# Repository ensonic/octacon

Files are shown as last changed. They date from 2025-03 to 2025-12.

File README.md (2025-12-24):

# Octacon
A midi controller tailored for bitwig with 8 endless pots, 8 buttons, 8 leds, 2 displays and a touch sensor.

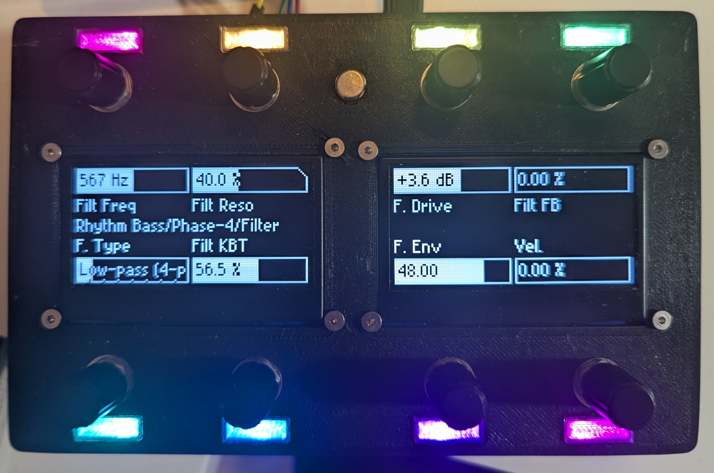
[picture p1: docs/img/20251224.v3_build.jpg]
wip image of the day


The latest [video tour](https://www.youtube.com/watch?v=5QIr6vOy6ok) can be watched on youtube.

# Getting started

## Flashing a release

* download and install [pictool](https://github.com/raspberrypi/picotool)
* download an octacon [firmware release](https://github.com/ensonic/octacon/releases) or [build it yourself](#code)
* connect octacon to usb
* flash the device using this command under linux:
  ```shell
  stty 1200 /dev/ttyACM0 && sleep 2 && picotool load -f ~/Downloads/firmware.uf2 && picotool reboot
  ```

## Installing the extension

Download an octacon [daw extension](https://github.com/ensonic/octacon/releases)
or [build it yourself](#code) and copy it into the `Extensions` folder of your
Bitwig Studio installation:
* Linux: ~/Bitwig Studio/Extensions/
* Mac: ~/Documents/Bitwig Studio/Extensions/
* Windows: %USERPROFILE%\Documents\Bitwig Studio\Extensions\

For Bitwig Studio > 3.4, you can also drag the file from your downloads into the Bitwig Studio window.

In Bitwig Studio, go to Settings > Controller and add a new one. Pick `ensonic`
as the vendor and select `Octacon` as the hardware. Ensure both midi ports have
`Octacon` or `Octacon MIDI 1` selected.

## Usage

TODO:
* active/passive mode
* control and navigation mode

# Hardware & Firmware

* raspberry pico 2
* 8 endless dual wiper potentiometers with buttons (RV142FPF-40B1-15F-0B20K-004)
* 3 analog multiplexers (e.g. CD74HC4051)
* 8 NeoPixel LEDs (WS2812x)
* 2 128x64 OLED displays connected via SPI
* 1 capacitive touch control

The `pcb` subfolder has the the schematics and the pcb files for [easyeda](https://easyeda.com/).
You should be able to import them into the Std Edition.

## Enclosure

The `3d` subfolder has openScad files and rendered STL for 3d printing.

The front_test.scad is mostly for prototyping:
Front view | Side View
:---------:|:---------:
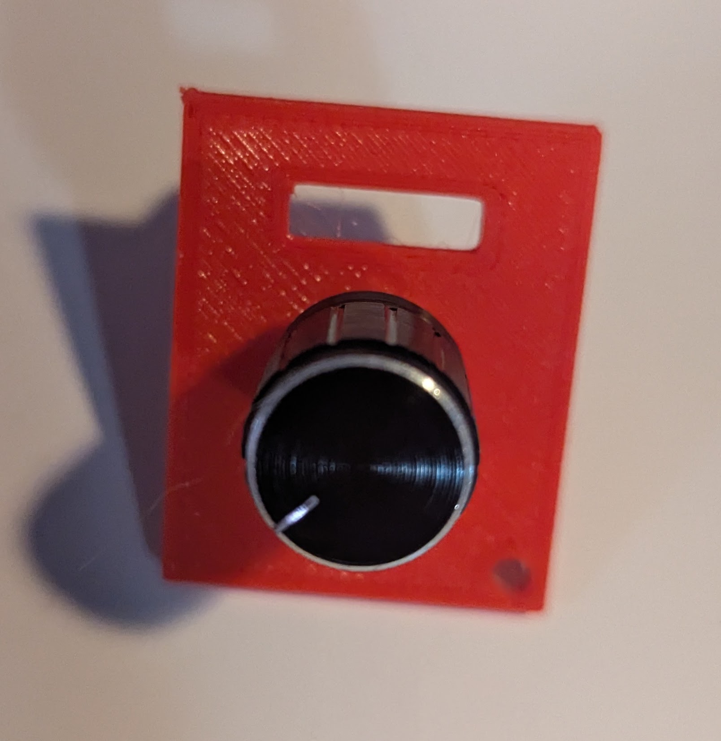
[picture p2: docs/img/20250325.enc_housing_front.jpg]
front
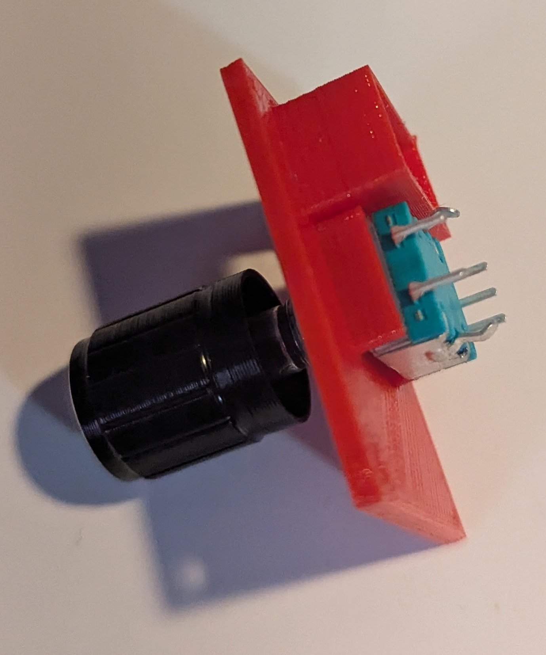
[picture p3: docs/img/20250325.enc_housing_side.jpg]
 | 

## MIDI implementation

Under Linux you can watch the communication using `asqedump`:

```shell
aseqdump -l | grep Octacon
 32:0    Octacon                          Octacon MIDI 1
aseqdump -p32:0
Source  Event                  Ch  Data
 32:0   Control change          0, controller 9, value 51
 32:0   Control change          0, controller 9, value 52
```

### Control changes

The encoders send 7bit values on cc 9 to 16. In 14-bit mode, the lsb is send on
cc 41 to 49.
The encoder buttons send values {0=off, 64=on} on cc 17 to 25.

### Sysex

Since Octacon uses usb midi and is a hobby project, we're using the `7D`
(prototyping, test, private use and experimentation). 

The following commands are implemented:
* 00: (recv) parameter names: `00 + <ix> + <len> + <name>`
  * id: 0...7
  * len: len of name, truncated to fit the display
  * name: ascii string data
* 01: (recv) pretty parameter value: `01 + <ix> + <len> + <name>`
  * id: 0...7
  * len: len of name, truncated to fit the display
  * name: ascii string data
* 02: (recv) daw connected? : `02 + <connected>`
  * connected: 0 = off, anything else = on
  * when off, parameter names and pretty values are generated
* 03: (recv) led pattern: `03 + <pattern>`
* 04: (recv) info string: `04 + <len> + <text>`
* 05: (recv) param ticks: `05 + <ix> <value>`
* 06: (recv) param flags: `05 + <ix> <flags>`
  * flags: bit field of:
    * 0: hasAutomation

# Code

## Firmware

The code uses [platformIO](https://platformio.org/). See [platformio.ini](platformio.ini) for the used libraries.

```shell
alias pio=$HOME/.platformio/penv/bin/pio
pio test
pio run -t upload
```

With regards to flashing from command-line, see:
  * https://github.com/maxgerhardt/platform-raspberrypi/issues/65
  * https://github.com/raspberrypi/picotool/issues/88

## DAW Extensions

The daw extension for Bitwig is written in java.

```shell
cd daw/bitwig
mvn install
```

# Debugging

Since we're using usb-midi, we can't use it for serial logging at the same time. I am simply using a nodemcu esp8266 as serial2. On the nodemcu connect EN to GND to disable the ESP. Then connect the nodemcu to the pico2 as follow:
nodemcu esp8266 | raspberry pico2 
:--------------:|:---------------:
GND  | GND
3.3V | 3.3V (optional)
TX   | UART1 TX, pin 6 
RX   | UART1 RX, pin 7

Now plug the nodemcu to usb and open /dev/ttyUSB0 to see the serial log.

# Links

I've got inspiration from many other places. Let me mention a few similar
projects:
* [Ottopot](https://gerotakke.de/ottopot/)

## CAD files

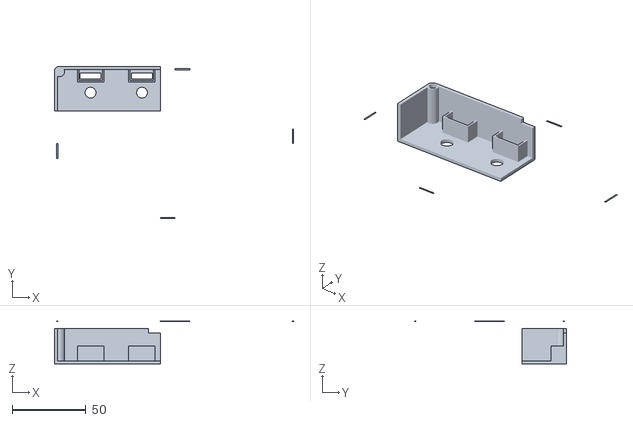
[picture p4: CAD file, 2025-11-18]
3d/v2/front.test.stl
162.6 x 103.4 x 29.1

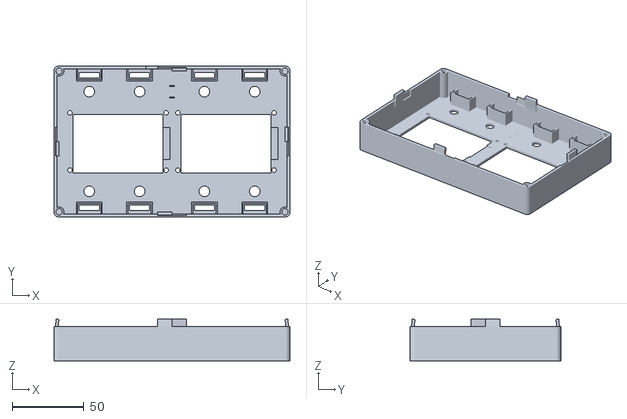
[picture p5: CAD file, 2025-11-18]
3d/v2/front.stl
164.0 x 104.8 x 29.1

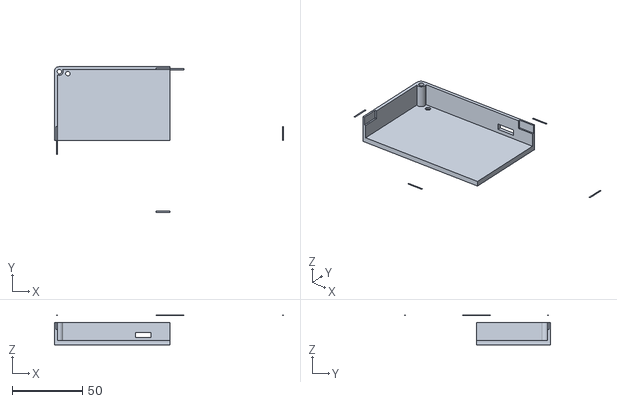
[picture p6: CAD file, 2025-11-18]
3d/v2/back.test.stl
162.6 x 103.4 x 21.1

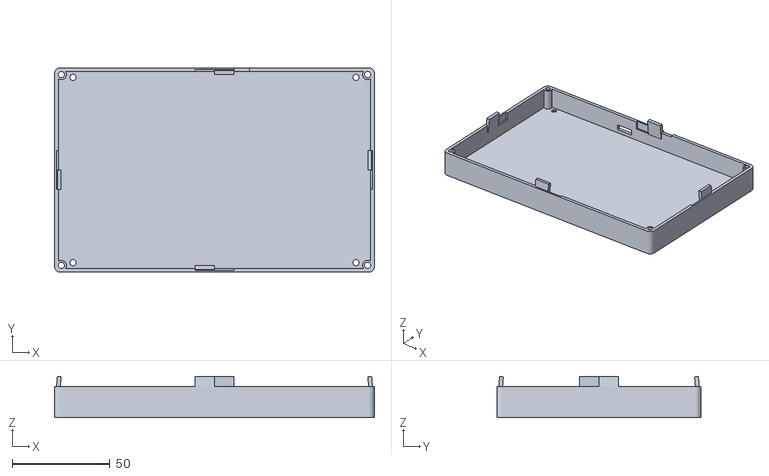
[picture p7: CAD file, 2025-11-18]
3d/v2/back.stl
164.0 x 104.8 x 21.1

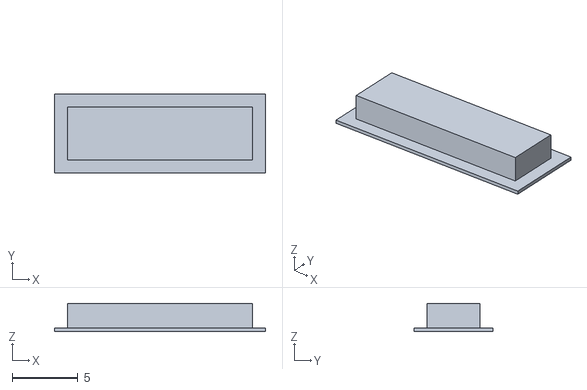
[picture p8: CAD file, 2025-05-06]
3d/v2/led.stl
16.0 x 6.00 x 2.12

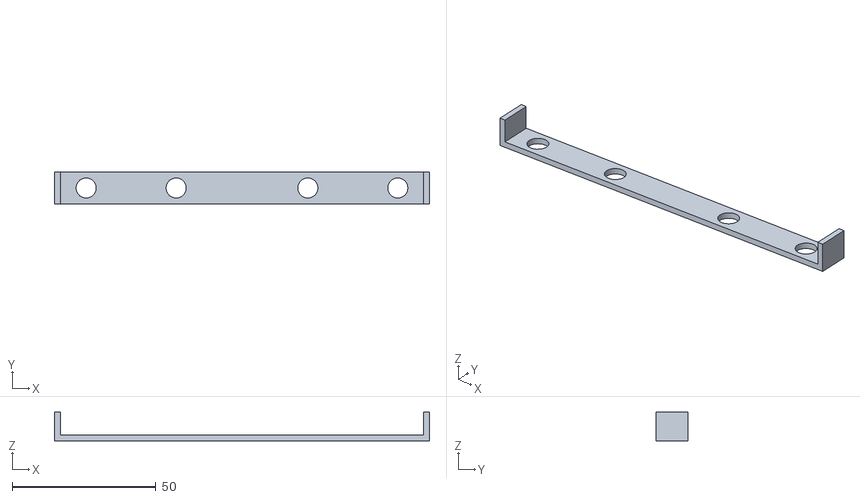
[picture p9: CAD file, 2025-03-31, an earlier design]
3d/v1/led_bracket.stl
130.2 x 11.0 x 10.0

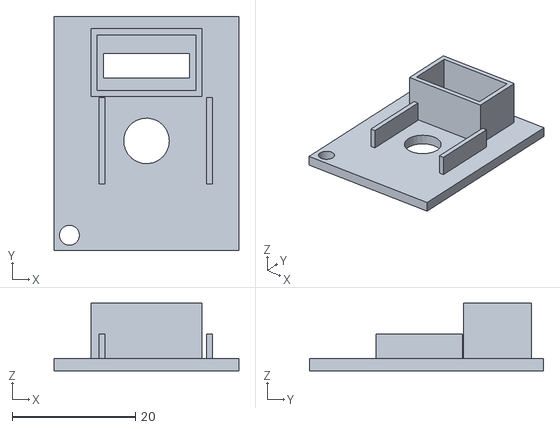
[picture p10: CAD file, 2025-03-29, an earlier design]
3d/v1/front_test.stl
30.0 x 38.0 x 11.0

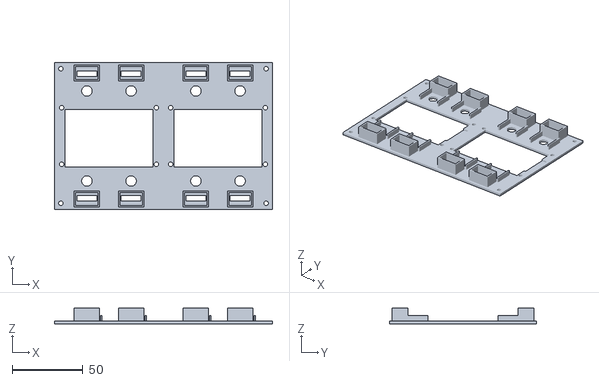
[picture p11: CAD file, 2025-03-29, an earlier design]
3d/v1/front.stl
154.0 x 104.0 x 11.0

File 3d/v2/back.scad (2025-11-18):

// octacon bottom case
// openscad -o back.stl back.scad
// f3d back.stl

// might be overridden by the Makefile to generate partial object
test=false;
if (test==true) {
    echo("TEST MODE ACTIVE", test);
}

// wall thickness
wd=2.0;
wd2=wd/2.0;

// case size
casew=160.0 + (2 * wd);
casew2=casew/2.0;
casehs=0.8; // leave some space to make the pcb fit
caseh=100.0 + (2 * wd) + casehs; 
caseh2=caseh/2.0;
// 20 mm screw - 4mm for inserts on the other side
// 16 mm is enough to hold the base pcb with the pico-2
cased=20-4;
cased2=cased/2.0;

// pcb size
pcbw=150.0;
pcbw2=pcbw/2.0;
pcbh=100.0;
pcbh2=pcbh/2.0;

// corners
corr=3;
cord=corr*2;
coff=corr/2;

// m3 screw holes
m3d=3.2; // extra size to cover 3d print thickness

// make it smooth
$fn=25;

difference() {
    union() {
        difference() {
            // main body
            cube([casew,caseh,cased],center=true);

            // space for inside
            translate([0,0,wd]) { cube([casew - (2.0 * wd), caseh - (2.0 * wd), cased-wd],center=true); }
            
            // rounded corners
            translate([-(casew2-corr),-(caseh2-corr),0]) { round_corner(cased+5, cord, -coff, -coff); }
            translate([+(casew2-corr),-(caseh2-corr),0]) { round_corner(cased+5, cord, +coff, -coff); }
            translate([-(casew2-corr),+(caseh2-corr),0]) { round_corner(cased+5, cord, -coff, +coff); }
            translate([+(casew2-corr),+(caseh2-corr),0]) { round_corner(cased+5, cord, +coff, +coff); }

            // holes for case screws
            translate([-(casew2-3.5),-(caseh2-3.5),0]) { screw_hole(cased, m3d); }
            translate([+(casew2-3.5),-(caseh2-3.5),0]) { screw_hole(cased, m3d); }
            translate([-(casew2-3.5),+(caseh2-3.5),0]) { screw_hole(cased, m3d); }
            translate([+(casew2-3.5),+(caseh2-3.5),0]) { screw_hole(cased, m3d); }
            
            // holes for base screws
            translate([-(pcbw2-2.5),-(pcbh2-2.5),0]) { screw_hole(cased, m3d); }
            translate([+(pcbw2-2.5),-(pcbh2-2.5),0]) { screw_hole(cased, m3d); }
            translate([-(pcbw2-2.5),+(pcbh2-2.5),0]) { screw_hole(cased, m3d); }
            translate([+(pcbw2-2.5),+(pcbh2-2.5),0]) { screw_hole(cased, m3d); }
            
            // usb hole (in inch grid: ~ 33-37)
            // micro-b plug body: max 11.7 mm * 8.5 mm
            // micro-b plug: 7mm x 3mm
            // on the pico-2 the micro-usb socket extends ~ 2mm beyond the board
            // hence leaving space for the plug should be enough
            // from the base of the board to top of the usb it is 16mm
            // TODO: we might need so hole on the front side too
            // z: 14mm - (cased2 - wd)
            // x (just need the middle): startpin=33, -1 (to start a zero), +3 (to get middle of the 6 pins)
            translate([-(pcbw2-((33-1)+3)*2.54),+caseh2, 15-(cased2-wd)]) { cube([8.0, wd*4, 4], center=true);}

            // debug header hole (in inch grid: 21-24)
            // 11.0 x 3.0 mm
            // the debug headers extend ~ 1 mm beyond the pcb
            // startpin=21, -1 (to start a zero), +2 (to get middle of the 4 pins)
            translate([-(pcbw2-((21-1)+2)*2.54),+caseh2,-cased2+(wd+5)]) { cube([11.0, wd*4, 3.5], center=true);}
            
            // groves for the matching ridges on the bottom
            translate([-(casew2-wd),+5,cased2]) { cube([wd,10,10], center=true); }
            translate([+(casew2-wd),-5,cased2]) { cube([wd,10,10], center=true); }
            translate([+5,-(caseh2-wd),cased2]) { cube([10,wd,10], center=true); }
            translate([-5,+(caseh2-wd),cased2]) { cube([10,wd,10], center=true); }
        }

        // tubes for case screws
        // 3.5 == (wd + wd) - .5 (thickness of screen wall / 2)
        translate([-(casew2-3.5),-(caseh2-3.5),wd2]) { screw_tube(cased-wd, m3d); }
        translate([+(casew2-3.5),-(caseh2-3.5),wd2]) { screw_tube(cased-wd, m3d); }
        translate([-(casew2-3.5),+(caseh2-3.5),wd2]) { screw_tube(cased-wd, m3d); }
        translate([+(casew2-3.5),+(caseh2-3.5),wd2]) { screw_tube(cased-wd, m3d); }

        // ridges for the matching groves on the bottom
        translate([-(casew2-wd),-5,cased2]) { rotate([0,+5,0]) { cube([wd,10,10], center=true); }}
        translate([+(casew2-wd),+5,cased2]) { rotate([0,-5,0]) { cube([wd,10,10], center=true); }}
        translate([-5,-(caseh2-wd),cased2]) { rotate([-5,0,0]) { cube([10,wd,10], center=true); }}
        translate([+5,+(caseh2-wd),cased2]) { rotate([+5,0,0]) { cube([10,wd,10], center=true); }}
    }

    // in test-mode generate only parts of the case
    translate([(test==true ? 0 : casew*10), 0, 0]) {
        translate([casew2,0,0]) { cube([casew, caseh+10, cased+10], center=true); }
        translate([0,-caseh2,0]) { cube([casew+10, caseh, cased+10], center=true); }
    }
}

module round_corner(h, d, x, y) {
    r=d/2;
    difference() {
        translate([x,y,0]) { cube([r+0.1,r+0.1,h], center=true); }
        cylinder(h=h+2, d=d, center=true);
    }    
}

module screw_tube(h, d) {
    difference() {
        cylinder(h=h, d=d+2, center=true);
        cylinder(h=h+2, d=d, center=true);
    }
}

module screw_hole(h, d) {
    union() {
        cylinder(h=h+5, d=d, center=true);
        translate([0, 0, -(h-wd)/2]) { cylinder(h=wd+.1, d1=d*2, d2=d, center=true); }
    }
}

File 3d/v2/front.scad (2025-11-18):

// octacon frontpanel
// openscad -o front.stl front.scad
// f3d front.stl

// might be overridden by the Makefile to generate partial object
test=false;
if (test==true) {
    echo("TEST MODE ACTIVE", test);
}

// wall thickness
wd=2.0;
wd2=wd/2.0;

// case size
casew=160.0 + (2 * wd);
casew2=casew/2.0;
casehs=0.8; // leave some space to make the pcb fit
casehs2=casehs/2.0;
caseh=100.0 + (2 * wd) + casehs; 
caseh2=caseh/2.0;
// 4mm for inserts, 16mm from top of panel to FPC mount
cased=24;
cased2=cased/2.0;

// pcb size
pcbw=150.0;
pcbw2=pcbw/2.0;
pcbw4=pcbw/4.0;
pcbh=100.0;
pcbh2=pcbh/2.0;

// display box
dw=62.5;
dw2=dw/2.0;
dw4=dw/4.0;
dh=40.5;
dh2=dh/2.0;
// display breakout board 
dbw=71;
dbw2=dbw/2.0;
dbh=44;
dbh2=dbh/2.0;
// account for asymmetric placement of display on breakout board
// dbh-dh = 3.5 : 3mm top, 0.5 mm bottom 
dho=-(3.0/2.0);

// led/pot positions on pcb
lppx1=17.5;
lppx2=52.5;
ppy=15.35;

// Alpha dual wiper potentiometers
ew=14.4;
eh1=9.7;
eh2=6.7;
eh=eh1+eh2;
eho=eh1-(eh/2.0); // shaft offset to center
er=3.7;  // shaft
// was 31.8, is now 34,65
em=pcbh2-ppy;

// leds
lw=14;
lh=4;
// pcb 2.2 mm space + 4 mm led hole
lm=46; // we need to cover 6mm from the top of the led&pots pcb
// with 13, we had only 7mm to the surface
// with 12.5 we have ~1 mm gap between pot & pcb
lsh=12.0;
lsh2=lsh/2.0;
lsg2=2;

// corners
corr=3;
cord=corr*2;
coff=corr/2;

// m3 screw holes
m3d=3.2; // extra size to cover 3d print thickness
m3r=m3d/2;
m3sd=.5+m3r;
// m4 insert holes
m4d=4.5;

// threaded inserts: outer diameter 5mm, depth 4mm

// make it smooth
$fn=25;

difference() {
    union() {
        difference() {
            // main body
            cube([casew,caseh,cased],center=true);

            // space for inside
            translate([0,0,wd]) { cube([casew - (2.0 * wd), caseh - (2.0 * wd), cased],center=true); }
            
            // rounded corners
            translate([-(casew2-corr),-(caseh2-corr),0]) { round_corner(cased+5, cord, -coff, -coff); }
            translate([+(casew2-corr),-(caseh2-corr),0]) { round_corner(cased+5, cord, +coff, -coff); }
            translate([-(casew2-corr),+(caseh2-corr),0]) { round_corner(cased+5, cord, -coff, +coff); }
            translate([+(casew2-corr),+(caseh2-corr),0]) { round_corner(cased+5, cord, +coff, +coff); }

            // displays
            translate([-pcbw4,  dho,0]) { cube([dw,dh,cased+5], center=true); }
            translate([-pcbw4+5,dho,.5]) { cube([dw,(dh*0.55),cased-1], center=true); }
            translate([+pcbw4,  dho,0]) { cube([dw,dh,cased+5], center=true); }
            translate([+pcbw4+5,dho,.5]) { cube([dw,(dh*0.55),cased-1], center=true); }

            // M3 holes for displays
            // left
            translate([-(pcbw4-(dbw2-m3sd)),-(dbh2-m3sd),0]) { cylinder(h=cased+5,r=m3r, center=true); }
            translate([-(pcbw4-(dbw2-m3sd)),+(dbh2-m3sd),0]) { cylinder(h=cased+5,r=m3r, center=true); }
            translate([-(pcbw4+(dbw2-m3sd)),-(dbh2-m3sd),0]) { cylinder(h=cased+5,r=m3r, center=true); }
            translate([-(pcbw4+(dbw2-m3sd)),+(dbh2-m3sd),0]) { cylinder(h=cased+5,r=m3r, center=true); }
            // right
            translate([+(pcbw4-(dbw2-m3sd)),-(dbh2-m3sd),0]) { cylinder(h=cased+5,r=m3r, center=true); }
            translate([+(pcbw4-(dbw2-m3sd)),+(dbh2-m3sd),0]) { cylinder(h=cased+5,r=m3r, center=true); }
            translate([+(pcbw4+(dbw2-m3sd)),-(dbh2-m3sd),0]) { cylinder(h=cased+5,r=m3r, center=true); }
            translate([+(pcbw4+(dbw2-m3sd)),+(dbh2-m3sd),0]) { cylinder(h=cased+5,r=m3r, center=true); }


            // leds
            // bottom row
            translate([0,-lm,0]) { 
                translate([-pcbw2+lppx2,0.0]) { cube([lw,lh,cased+5], center=true); }
                translate([-pcbw2+lppx1,0.0]) { cube([lw,lh,cased+5], center=true); }
                translate([+pcbw2-lppx2,0.0]) { cube([lw,lh,cased+5], center=true); }
                translate([+pcbw2-lppx1,0.0]) { cube([lw,lh,cased+5], center=true); }
            }
            // top row
            translate([0,lm,0]) { 
                translate([-pcbw2+lppx2,0.0]) { cube([lw,lh,cased+5], center=true); }
                translate([-pcbw2+lppx1,0.0]) { cube([lw,lh,cased+5], center=true); }
                translate([+pcbw2-lppx2,0.0]) { cube([lw,lh,cased+5], center=true); }
                translate([+pcbw2-lppx1,0.0]) { cube([lw,lh,cased+5], center=true); }
            }

            // potentiometers
            // bottom row
            translate([0,-em,0]) { 
                translate([-pcbw2+lppx2,0,0]) { cylinder(h=cased+5,r=er, center=true); }
                translate([-pcbw2+lppx1,0,0]) { cylinder(h=cased+5,r=er, center=true); }
                translate([+pcbw2-lppx2,0,0]) { cylinder(h=cased+5,r=er, center=true); }
                translate([+pcbw2-lppx1,0,0]) { cylinder(h=cased+5,r=er, center=true); }
            }
            // top row
            translate([0,em,0]) { 
                translate([-pcbw2+lppx2,0,0]) { cylinder(h=cased+5,r=er, center=true); }
                translate([-pcbw2+lppx1,0,0]) { cylinder(h=cased+5,r=er, center=true); }
                translate([+pcbw2-lppx2,0,0]) { cylinder(h=cased+5,r=er, center=true); }
                translate([+pcbw2-lppx1,0,0]) { cylinder(h=cased+5,r=er, center=true); }
            }

            // tube-holes for case-inserts
            translate([-(casew2-3.5),-(caseh2-3.5),wd2]) { insert_tube_hole(cased-wd, m4d); }
            translate([+(casew2-3.5),-(caseh2-3.5),wd2]) { insert_tube_hole(cased-wd, m4d); }
            translate([-(casew2-3.5),+(caseh2-3.5),wd2]) { insert_tube_hole(cased-wd, m4d); }
            translate([+(casew2-3.5),+(caseh2-3.5),wd2]) { insert_tube_hole(cased-wd, m4d); }

            // groves for the matching ridges on the bottom
            translate([-(casew2-wd),+5,cased2]) { cube([wd,10,10], center=true); }
            translate([+(casew2-wd),-5,cased2]) { cube([wd,10,10], center=true); }
            translate([+5,-(caseh2-wd),cased2]) { cube([10,wd,10], center=true); }
            translate([-5,+(caseh2-wd),cased2]) { cube([10,wd,10], center=true); }

            // holes for split pin legs: 8mm apart, 3mm width, 
            // position so that we can bend the legs to the middle
            translate([0,em-4,0]) { cube([3.5,0.6,cased+10], center=true); }
            translate([0,em+4,0]) { cube([3.5,0.6,cased+10], center=true); }
            
            // usb hole (see back.scad for positioning, nneds to be x-flipped!)
            translate([+(pcbw2-((33-1)+3)*2.54),+caseh2, (cased-3.0)-(cased2-wd)]) { cube([8.0, wd*4, 4], center=true);}
            
        }

        // tubes for case screw inserts
        // 3.5 == (wd + wd) - .5 (thickness of screen wall / 2)
        translate([-(casew2-3.5),-(caseh2-3.5),wd2]) { insert_tube(cased-wd, m4d); }
        translate([+(casew2-3.5),-(caseh2-3.5),wd2]) { insert_tube(cased-wd, m4d); }
        translate([-(casew2-3.5),+(caseh2-3.5),wd2]) { insert_tube(cased-wd, m4d); }
        translate([+(casew2-3.5),+(caseh2-3.5),wd2]) { insert_tube(cased-wd, m4d); }

        // led boxes
        // bottom row
        translate([0,-(lm+lsg2-1),-(cased2-lsh2)]) {
            translate([-pcbw2+lppx2,0,0]) { led_shield(); }
            translate([-pcbw2+lppx1,0,0]) { led_shield(); }
            translate([+pcbw2-lppx2,0,0]) { led_shield(); }
            translate([+pcbw2-lppx1,0,0]) { led_shield(); }
        }
        // top row
        translate([0,+(lm+lsg2-1),-(cased2-lsh2)]) {
            translate([-pcbw2+lppx2,0,0]) { led_shield(); }
            translate([-pcbw2+lppx1,0,0]) { led_shield(); }
            translate([+pcbw2-lppx2,0,0]) { led_shield(); }
            translate([+pcbw2-lppx1,0,0]) { led_shield(); }
        }       

        // ridges for the matching groves on the bottom
        translate([-(casew2-wd),-5,cased2]) { rotate([0,+5,0]) { cube([wd,10,10], center=true); }}
        translate([+(casew2-wd),+5,cased2]) { rotate([0,-5,0]) { cube([wd,10,10], center=true); }}
        translate([-5,-(caseh2-wd),cased2]) { rotate([-5,0,0]) { cube([10,wd,10], center=true); }}
        translate([+5,+(caseh2-wd),cased2]) { rotate([+5,0,0]) { cube([10,wd,10], center=true); }}
    }

    // in test-mode generate only parts of the case
    translate([(test==true ? 0 : casew*10), 0, 0]) {
        // +6 to have the full split-pins in there
        //translate([casew2+6,0,0]) { cube([casew, caseh+10, cased+10], center=true); }
        translate([casew2-10,0,0]) { cube([casew, caseh+10, cased+10], center=true); }
        translate([0,22-caseh2,0]) { cube([casew+10, caseh, cased+10], center=true); }
    }
}

// modules

module round_corner(h, d, x, y) {
    r=d/2;
    difference() {
        translate([x,y,0]) { cube([r+0.1,r+0.1,h], center=true); }
        cylinder(h=h+2, d=d, center=true);
    }    
}
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

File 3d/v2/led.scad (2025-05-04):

// octacon led diffusor
// alias openscad=~/Applications/OpenSCAD-2021.01-x86_64.AppImage
// openscad -o led.stl led.scad
// f3d led.stl
//
// slicer settings:
// - normal (0.15mm)
// - infill pattern=tri-hexagon
//
// Use transparent PLA

// wall thickness
wd=2.0;

// leds
lw=14;
lh=4;

union() {
    cube([lw,lh, wd], center=true);
    translate([0,0,-wd/2]) { cube([lw+2,lh+2,0.25],center=true); }
}

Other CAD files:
3d/v1/front.scad
3d/v1/front_test.scad
3d/v1/led_bracket.scad

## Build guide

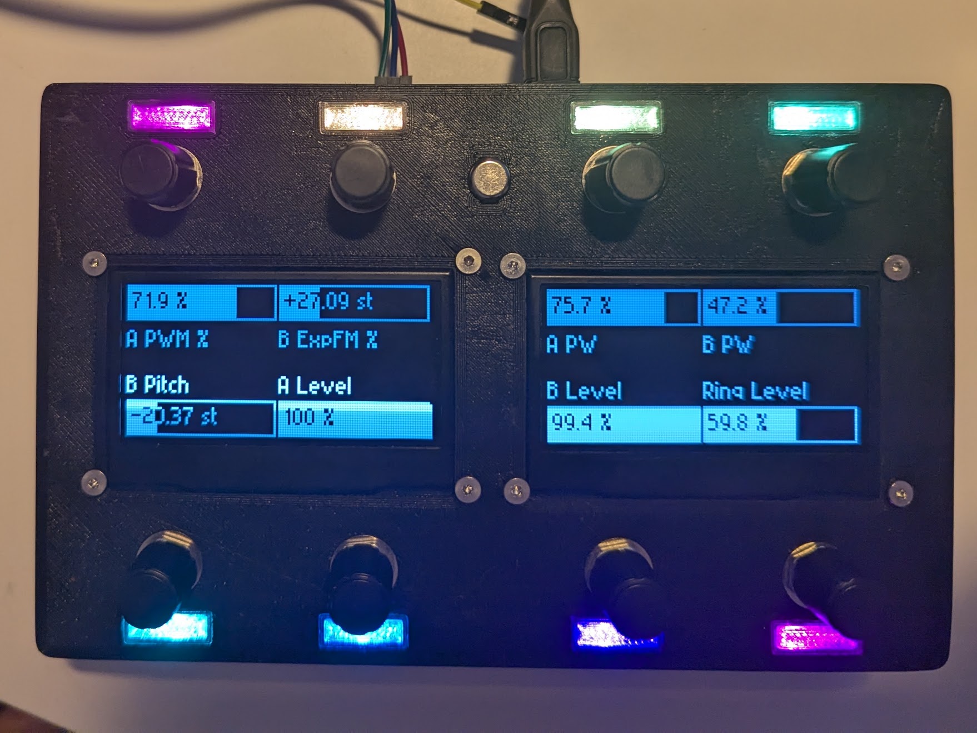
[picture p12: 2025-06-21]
docs/img/20250614.v3_build.jpg

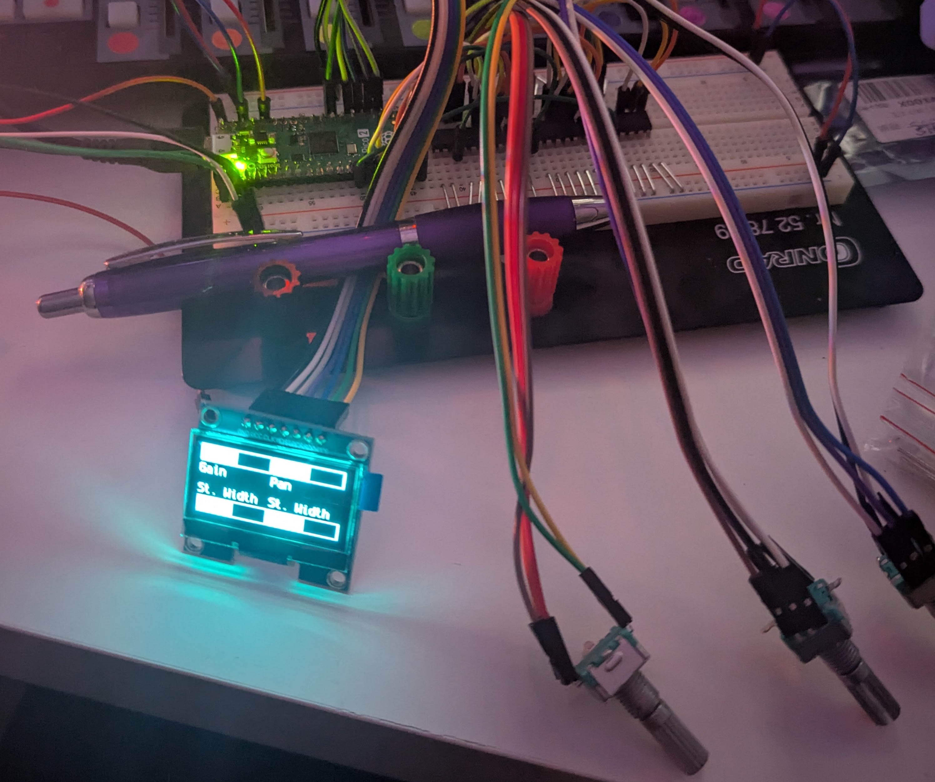
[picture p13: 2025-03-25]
docs/img/20250325.proto_build.jpg

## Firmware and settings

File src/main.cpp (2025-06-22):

// octacon midi controller

#include <config.h>

// hardware variant to build
#if HW_VER == 1
#include <hw.v1.h>
#elif HW_VER == 2
#include <hw.v2.h>
#endif


static boolean active = false;

// callbacks

static void valueCB(unsigned int ix,int value,int delta) {
    if (!active) return;
    dbg.printf("Knob[%u]: Value = %d | Delta = %d\n", ix, value, delta);
    ui.setValue(ix, value);
    mio.sendValueCC(ix, value);
}

static void buttonCB(unsigned int ix, int state) {
    if (!active) return;
    dbg.printf("Button:[%u]; State= %d\n", ix, state);
    mio.sendButtonCC(ix, state*64);
}

void setup() {
    unsigned long ts0 = millis();
    leds.begin(); // call early to reset to black
    mio.init(); // call early to ensure usb-id is set

    dbg.init();
    dbg.println("Setup start");

    pinMode(LED_BUILTIN, OUTPUT);

    ui.init();

    knobs.setLimits(0,VAL_MAX);
    knobs.setValue(VAL_MAX/2);
    knobs.attachButtonCallback(buttonCB);
    knobs.attachValueCallback(valueCB);
    knobs.begin();

    capsense.begin();

    leds.setBrightness(0.05);
    ui.begin();
    dbg.printf("Setup done: %u ms\n", millis()-ts0);
}

// run midi at full speed
// don't poll the knobs too quickly though
void loop() {
    unsigned long m=millis();
    static unsigned long tk = 0;
    if (m - tk > 20) {
        knobs.tick();
        tk = m;
    }

    mio.tick();

    static unsigned long tb = 0;
    static bool blink = false;
    if (m - tb > 500)  {
        digitalWrite(LED_BUILTIN, blink);
        blink = !blink;
        tb = m;
        /* DEBUG
        leds.SetBrightness((blink ? 0.2 : 0.3));
        */
    }

    static unsigned long tt = 0;
    static unsigned long touch_wait = 0;
    static boolean touched = false;
    if (m - tt > touch_wait)  {
        touch_wait = 0;
        // csv is the discharge time, if long, the sensor has been touched
        unsigned long csv = capsense.touch();
        //dbg.printf("CapSensor: %lf µs\n", csv);
        if (!touched && csv > 1000) {
            touched = true;
            touch_wait = 250;
            dbg.printf("CapSensor: touch    : %lu µs\n", csv);
            active = !active;
            leds.setBrightness(active ? 0.3 : 0.05);
        } else if (touched && csv < 250) {
            touched = false;
            touch_wait = 250;
            dbg.printf("CapSensor: released : %lu µs\n", csv);
        }
        tt = m;
    }
}

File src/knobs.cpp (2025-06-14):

// knob handlers code

#include <debug.h>
#include <knobs.h>

#include <math.h>

extern Debug dbg;

// use analogReadResolution(12); to activate this resolution, default is 10
static const int ADC_100_PCT = (1<<12);
static const int ADC_50_PCT = (ADC_100_PCT>>1);

/* which pot to debug (press button to switch)
static int dbgix=0;
static int vami=ADC_100_PCT,vama=0;
static int vbmi=ADC_100_PCT,vbma=0;
*/

Knobs::Knobs(admux::Mux *vala,admux::Mux *valb, admux::Mux *btn, int8_t *kmap) : vala(vala), valb(valb), btn(btn) , kmap(kmap) {
    float threshold_pct = (float)threshold / (float)ADC_100_PCT;
    for (unsigned i = 0; i < numParams; i++) {
        pots[i].threshold = threshold_pct;
    }
}

void Knobs::begin(void) {
    analogReadResolution(12);
    tick();
}

void Knobs::tick(void) {
    for (unsigned i = 0; i < numParams; i++) {
        // it is enough to drive one multiplexer address, as we use the same 
        // S{0,1,2} pins for all 3 multiplexers
        /*
        */
        vala->channel(kmap[i]);
        delayMicroseconds(1); // let  ADC settle

        auto va = mavgA[i].update(vala->read());
        auto vb = mavgB[i].update(valb->read());
       
        // see plot.py
        /*if (i==0) {
            dbg.printf("plt:%d,%d\n", va, vb);
        }*/
        /* DEBUG
        if (i == dbgix) {
            if (va > vama) vama=va;
            else if (va < vami) vami=va;
            if (vb > vbma) vbma=vb;
            else if (vb < vbmi) vbmi=vb;
        } */

        float vaf = (float)(va-ADC_50_PCT)/(float)ADC_50_PCT;
        float vbf = (float)(vb-ADC_50_PCT)/(float)ADC_50_PCT;
        int delta = scale * pots[i].update(vaf, vbf);
        if (vcb && abs(delta) > 0) {
            lastTs[i] = millis();
            int v=values[i];
            if ( v + delta > maxV) {
                //dbg.printf("clip upper: %d + %d\n", v, delta);
                delta = maxV - values[i];
            } else if (v + delta < minV) {
                //dbg.printf("clip lower: %d + %d\n", v, delta);
                delta = minV - values[i];
            }
            if (abs(delta) > 0) {
                v += delta;
                vcb(i, v, delta);
                /* DEBUG
                if (i == dbgix) {
                    dbg.printf("%1d: v=%5d, d=%+5d, va=%5d..%5d..%5d, vb=%5d..%5d..%5d\n",
                        i, v, delta, vami,va, vama, vbmi, vb, vbma);
                } */
            }
            values[i] = v;
        }
 
        auto button = btn->read();
        if (bcb && button != buttons[i]) {
            buttons[i] = button;
            bcb(i, button);
            /* DEBUG
            if (button == 0) {
                vami=vbmi=ADC_100_PCT;
                vama=vbma=0;
                dbgix = i;
            } */
        }
    }    
}

void Knobs::setLimits(int mi, int ma) {
    minV = mi;
    maxV = ma;
    scale = (float)((1+ma)-mi);
}

void Knobs::setValue(int val) {
    for (unsigned i = 0; i < numParams; i++) {
       values[i] = val;
    }
}

void Knobs::setValue(unsigned ix, int val) {
    if ((millis() - lastTs[ix]) < 100) return;

    values[ix] = val;
}

int Knobs::getValue(unsigned ix) {
    return values[ix];
}

void Knobs::attachValueCallback(valueCallback_t callback) {
    vcb = callback;
}

void Knobs::attachButtonCallback(buttonCallback_t callback) {
    bcb = callback;
}

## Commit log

2025-03-23 Add draft for front-panel.
    [front.scad, front.stl]
2025-03-23 Initial display layout.
    Draw actual values for the first 4 encoders.
2025-03-24 Switch to bitwig colors.
    Switch leds to use bitwig colors.
2025-03-24 Improve the 3d models.
    Add a small version of the front-panel for testing. Add a led-holder.
    [front.scad, front.stl, front_test.scad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]
2025-03-24 Update parameter handling.
    * drop color led changes (was only temp for debugging)
    * prep draw code to get param names and do ix mappiing
    * init params from midi cc
2025-03-25 Add support for pretty printed values.
    The small display now show the value as in the DAW.
2025-03-25 Code cleanups
    * update comments
    * use shorter text to not clobber other text
    [main.cpp]
2025-03-25 Add cc for button presses
2025-03-26 'Repair' printf.
    Yes, there are limitations, but ...
2025-03-27 Expand TOOD comment for encoder change
2025-03-27 Better placement of the corner M3 screw holes.
    [front.scad, front.stl, front_test.scad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]
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2025-03-29 Update 3d models.
    * fix potentionmeter supprots for frontend
    * add display mounting holes
    * add spacer for display breakout pins
    [front.scad, front.stl, front_test.scad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]
2025-03-30 Switch to endless spotentiometers.
    Note: this is work in progress.
2025-03-30 add csv dumps for endles-pots.
    Improve the test, but sadly still broken.
    [main.cpp]
2025-03-31 Update width.
    [led_bracket.scad, led_bracket.stl]
2025-03-31 Replace EndlessPotentiometer code.
    Use atan2 which is close enough for this purpose.
    [knobs.cpp]
2025-04-01 Add a python plotter for the pot signals.
    Sadly it is quite sloppy and also seem to not properly initialize the
    connection.
    [knobs.cpp, plot.py]
2025-04-02 Ignore value changes via midi during interaciton.
    This would quikcly cause jitter due to feedback.
    [knobs.cpp]
2025-04-02 Fix 2 bugs in the knob handling.
    * we need to divide by 2*PI as values range from -pi...pi
    * we need to store the value also if we skip the large changes
    [knobs.cpp]
2025-04-03 Fix 350<>0 drees transitions.
    [knobs.cpp]
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2025-04-06 Move cmt to adc resolution over.
    This is where we configure the hw.
2025-04-06 Improve wiring.
    * don't use adc-gnd for the button mux.
    * add chip labels
2025-04-06 Switch knobs abck to EndlessPotentiometer class.
    Now that we extracted the code, we can switch to it. We keep the ADC res
    in know and also setting the scaling (sensitivity).
2025-04-08 Add schematic from easyeda.
2025-04-15 Init leds early and dim more.
2025-04-16 Fix multiplexer pin assingment
    [main.cpp]
2025-04-16 Fix bigus variable name.
    [knobs.cpp]
2025-04-17 Switch to atan2f to avoid conversion.
2025-04-18 Increase threashold to avoid jitter of params.
2025-04-18 Also use numParams for the ledCount
2025-04-18 Update led type to rgb.
2025-04-18 Small update for the led colors
2025-04-18 Add led panel-led pulse to check stability of colors.
    [main.cpp]
2025-04-18 Swap led order to match hw-build
    I'd chained the last 4 in reveresed order to reduce the wiring mess.
    [main.cpp]
2025-04-21 Experiemnt with a capacitive touch sensor.
    We'd like to use it to togle the device between active/inactive.
2025-04-21 Move led code to leds class.
    Also use constantes for pin-numbers to improve code readability.
2025-04-21 Use the touch snesor to togle led brightness.
    Thats for testing only, but better than the serial debug spew.
2025-04-29 Switch to my FastCapacitiveSensor fork.
    I've send PRs too.
2025-04-30 Use unsigned long for the timers.
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2025-05-01 Misc cleanups
    * more type fixes for timestamps
    * move led enablement last in setup
    * fix comment typo
    [main.cpp]
2025-05-01 Make space for next gen.
    [front.scad, front.stl, front_test.scad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]
2025-05-01 Implement active/inactive mode.
    The knobs can cause random parameter changes. We're now stating
    in-active, that is we don't send midi-changes. We also use a capacitive
    touch sensor to activate the controlerl and also to disable it again.
2025-05-03 Start v2 case design.
    [back.scad, front.scad]
2025-05-04 Add model for led diffusors.
    [led.scad, led.stl]
2025-05-04 Adding most details to v2 encusure
    [back.scad, back.stl, front.scad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]
2025-05-04 Connector hole placement.
    [back.scad, back.stl]
2025-05-06 Improve 3d dev-flow
    * add Makefiles
    * add a test-mode where we generate a sub-part for easy 3d-print testing
    [back.scad, back.stl, back.test.stl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]
2025-05-07 Improve case models.
    * add ridges and groves to make sure the case fits better.
    * tweak the usb connector hole
    [back.scad, back.stl, back.test.stl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]
2025-05-10 Add holes for split-pin.
    We'll use that for the touch sensor.
    [front.scad]
2025-05-11 update new board height and also update renderings
    [back.scad, back.stl, back.test.stl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]
2025-05-17 3d model updates.
    * update udb hole position (also add gap for front side)
    * rotate split pin legs to allow bending them
    [back.scad, back.stl, back.test.stl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]
2025-05-18 Adjust 3d model after 1st fit test.
    * added a bit of inner spacing for the height
    * fixed position of the debug header.
    [back.scad, back.stl, back.test.stl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]
2025-05-18 Increase the spacing on the height a bit.
    This is now 0.4 mm on each side. This will make the usb connector sit a
    bit deeper though.
    [back.scad, back.stl, back.test.stl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]
2025-05-20 Modularize the code for hardware versions.
    Add one for the protoboard (v1) and one for the pcb (v2).
2025-05-29 More adjustedments from some test prints.
    * adjust hole sizes for inserts.
    * adjusts width for split pins
    * increase height for led covers
    [back.scad, back.stl, back.test.stl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]
2025-06-05 Fix type for millis.
    [main.cpp]
2025-06-08 Update 3d modules
    * shift usb hole
    * add missing display screw holes
    [back.scad, back.stl, back.test.stl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]
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2025-06-14 Account for flipped knob order for bottom strip.
    [knobs.cpp]
2025-06-21 Start implementing nav mode.
    * the controller script handles button presses
    * on button press it sends a mode-change sysex
    * the device switches the led-colors on button
    press
2025-06-21 Reset led pattern when exiting daw-mode.
2025-06-22 Show info in control mode
    Collect Track/Device/Page name from ctrl-script and show. Simplify string splitting code for info strings.
2025-07-02 Add schematics + pcb files.
    Remove the outdated and hand-drawn schematics.
2025-07-06 Fix Test clipping.
    We drew over the bars for the pretty values, but also cut the bottom of the text too early.
2025-07-06 Refactor info-strings.
    Now switching modes will also update it.
2025-07-06 Start implementing nav mode
    Implement it for switching controller pages. Also fix a couple of bug wrt to mode switching.
2025-07-07 Attempt to implement track/device nav.
    We get the values, but we can't navigate (yet)
2025-07-20 Add 4 mm to front case height.
    This will make the insides less cramped.
    [front.scad]
2025-07-20 Rework the clips on the case.
    The clips are there to make sure the sides are well aligned. The
    previous version was not ridgid enough.
    [back.scad, back.stl, back.test.stl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]
2025-11-18 3d: make debug hole a bit taller
    I had to file the previous versions to account for tolerances with the
    placed pcb.
    [back.scad, back.stl, back.test.stl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]
2025-11-18 3d: make tubes on front part bit slimmer
    This should improve the fit of the leds+pots pcb.
    [front.scad, front.stl, front.test.stl]
2025-12-22 Get both track and device nav to work
    It has been a bit of trial and error, but it now starts to work.
2025-12-22 Expand the README
    * start all headings upper case
    * start with more end-user focused docs
2025-12-24 Add automation hints to UI.
    Parameter boxes have a cut-out triangle to indicate that the parameter
    has automation attached.
    The midi message can actually transport 6 additioanl flags.
    Refactor draing code to replace some copy & paste.
    Fixes #1
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
